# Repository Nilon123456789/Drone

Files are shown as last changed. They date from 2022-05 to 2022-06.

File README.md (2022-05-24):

# Drone
An open source multi-use drone made with arduino and 3d printing

Features

- Simple to use
- Easily editable
- Versatile

## Libraries

This project uses these following libraries

| Library | GitHub page |
| --- | --- |
| TinyMPU6050 | https://github.com/gabriel-milan/TinyMPU6050 |
| Servo | https://github.com/arduino-libraries/Servo |

## Require parts
Wearing or 3d printed part may need to be modified to suit other parts

| Part | quantity |
| --- | --- |
| Arduino nano | 1 |
| MPU 6050 | 1 |
| Pref board | 150x100mm |
| PLA or PETG | ≈ 1 kg |
| Jumper wire | pqt. 10 |
| Break away pins | pqt 25|
| zip ties | pqt 30 |
| M2.5 stand off | 6 |
| M3 nuts | 32 |
| M3x12 bolts | 32 |

## Build instruction
Coming later

## 3D printing instruction 
Coming later

## Programation and Setup
Coming later

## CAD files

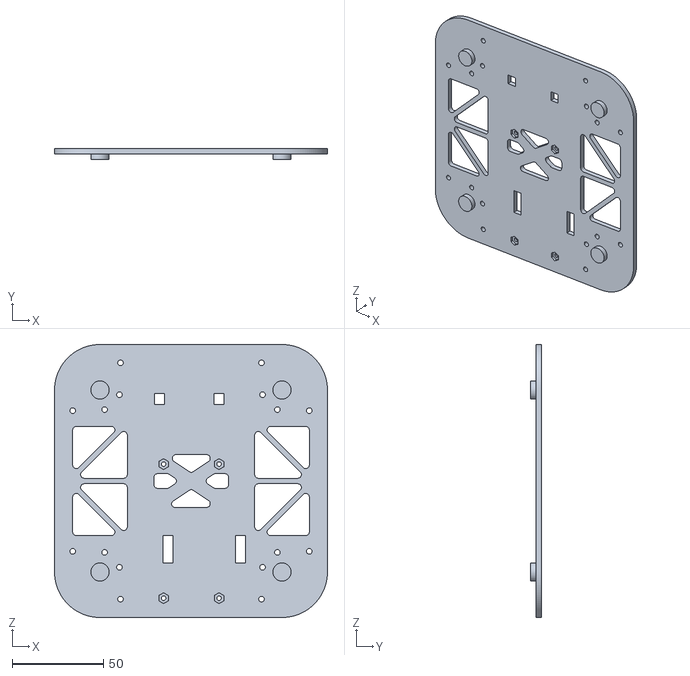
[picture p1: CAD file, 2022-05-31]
STL files/Drone/01-Main_Frame.stl
150.0 x 6.00 x 150.0

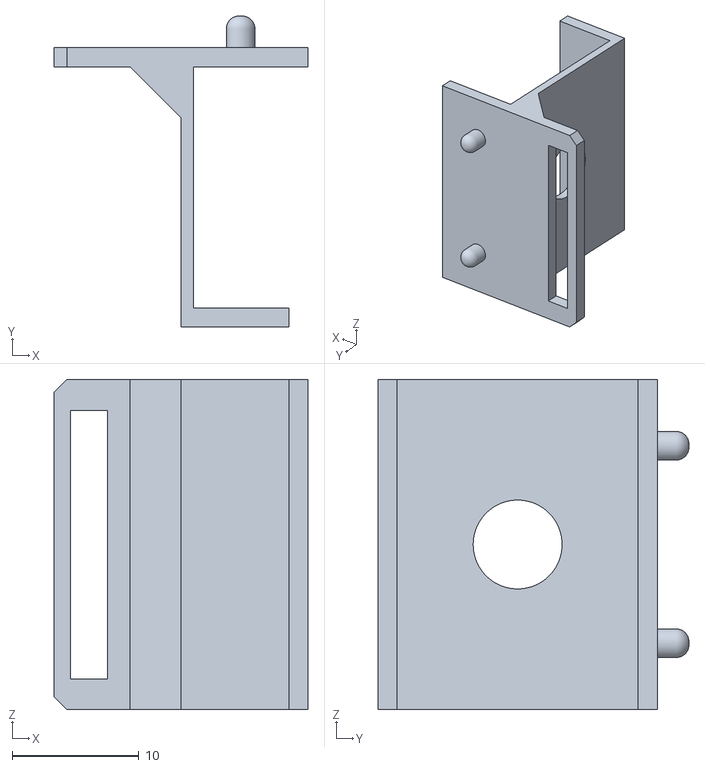
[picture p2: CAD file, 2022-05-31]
STL files/Balance/01-MPU_Holder.stl
20.0 x 24.5 x 26.0

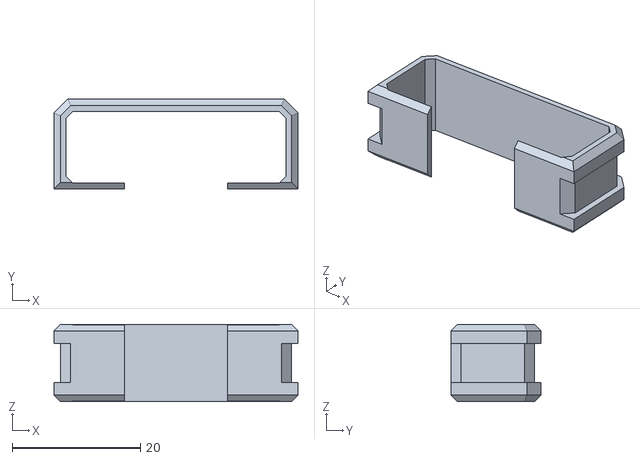
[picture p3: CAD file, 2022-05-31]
STL files/Drone/03-RC_Holder.stl
38.0 x 14.0 x 12.0

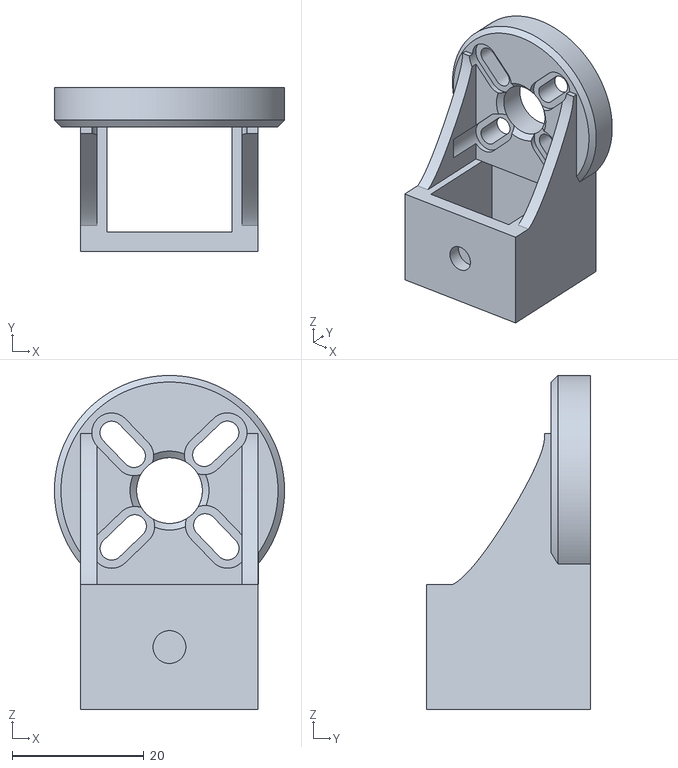
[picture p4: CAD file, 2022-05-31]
STL files/Balance/02-Motor_Holder.stl
35.0 x 25.0 x 50.8

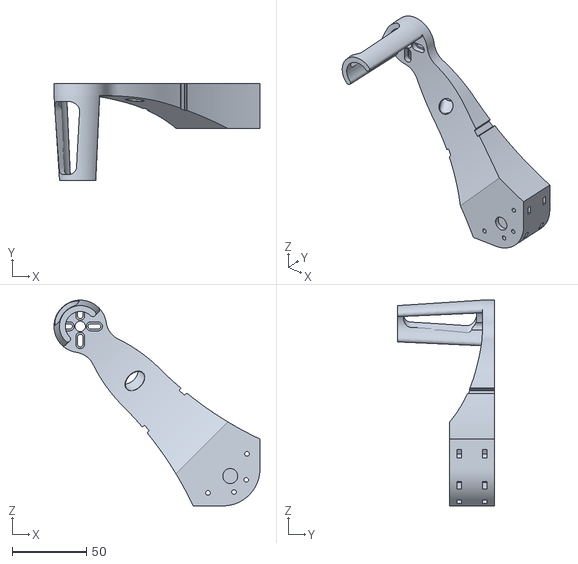
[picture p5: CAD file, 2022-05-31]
STL files/Drone/02-Arms.stl
138.6 x 65.0 x 138.5

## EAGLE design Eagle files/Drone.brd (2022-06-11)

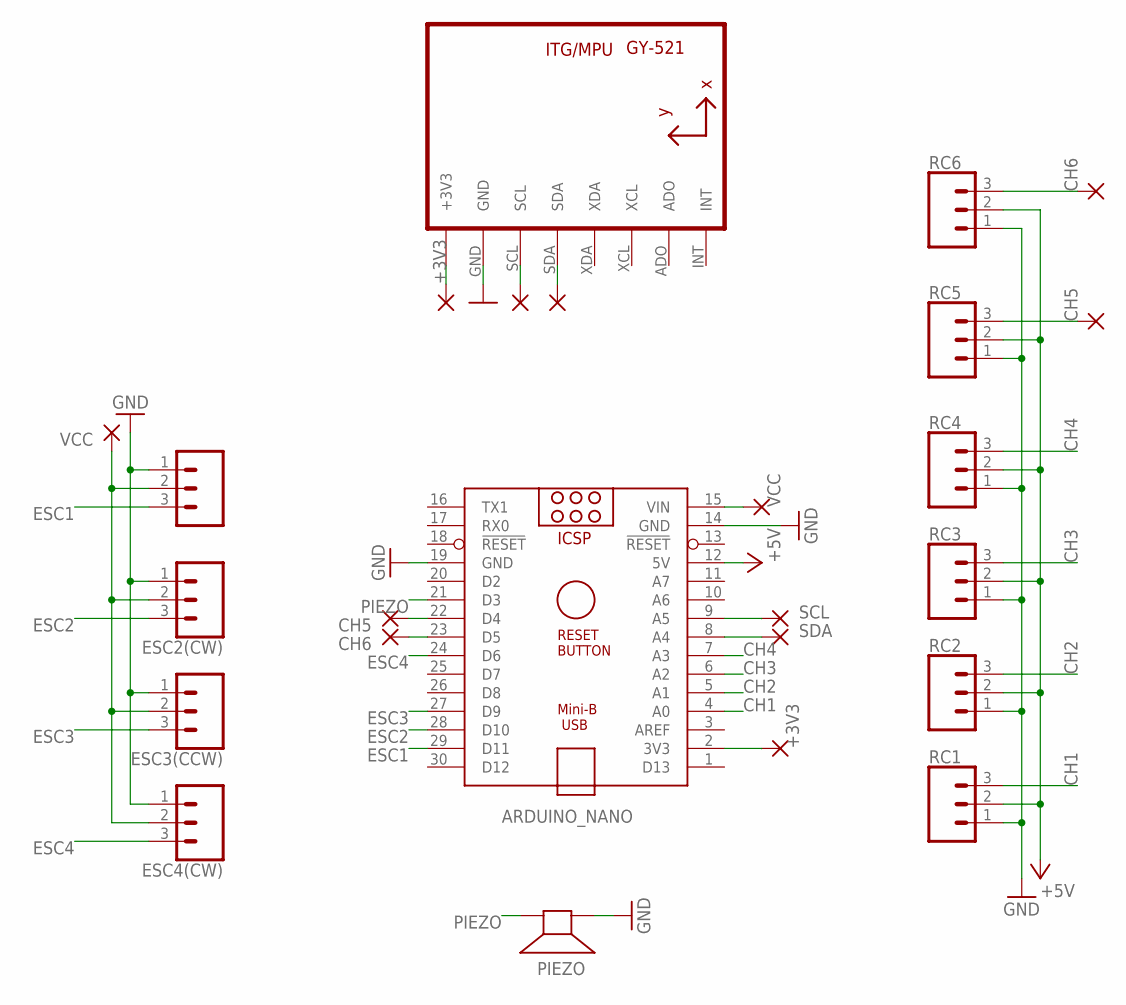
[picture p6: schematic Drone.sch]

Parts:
+3V3-1, +3V3-2: +3V3; 1,6/0,8
ARDUINO_NANO: ARDUINO_NANO
CH5, CH5-2, CH6, CH6-2: SCL; 1,6/0,8
ECS1(CCW): CONN_03; 1X03
ESC2(CW), ESC3(CCW), ESC4(CW): CONN_03; 1X03
PIEZO: SPEAKER/AL60P; AL60P
RC1, RC2, RC3, RC4, RC5, RC6: CONN_03; 1X03
SCL: SCL; 1,6/0,8
SCL-2: SCL; 1,6/0,8
SDA: SDA; 1,6/0,8
SDA-2: SDA; 1,6/0,8
U1: GY-521MPU6050; GY-521
VCC-1, VCC-2: VCC; 1,6/0,8

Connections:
+3V3: +3V3-1.1, +3V3-2.1, ARDUINO_NANO.2 (3V3), U1.VCC (+3V3)
+5V: ARDUINO_NANO.12 (5V), RC1.2, RC2.2, RC3.2, RC4.2, RC5.2, RC6.2
CH1: ARDUINO_NANO.4 (A0), RC1.3
CH2: ARDUINO_NANO.5 (A1), RC2.3
CH3: ARDUINO_NANO.6 (A2), RC3.3
CH4: ARDUINO_NANO.7 (A3), RC4.3
CH5: ARDUINO_NANO.22 (D4), CH5.1, CH5-2.1, RC5.3
CH6: ARDUINO_NANO.23 (D5), CH6.1, CH6-2.1, RC6.3
ESC1: ARDUINO_NANO.29 (D11), ECS1(CCW).3
ESC2: ARDUINO_NANO.28 (D10), ESC2(CW).3
ESC3: ARDUINO_NANO.27 (D9), ESC3(CCW).3
ESC4: ARDUINO_NANO.24 (D6), ESC4(CW).3
GND: ARDUINO_NANO.14 (GND), ARDUINO_NANO.19 (GND), ECS1(CCW).1, ESC2(CW).1, ESC3(CCW).1, ESC4(CW).1, PIEZO.1 (+), RC1.1, RC2.1, RC3.1, RC4.1, RC5.1, RC6.1, U1.GND
PIEZO: ARDUINO_NANO.21 (D3), PIEZO.2 (-)
SCL: ARDUINO_NANO.9 (A5), SCL.1, SCL-2.1, U1.SCL
SDA: ARDUINO_NANO.8 (A4), SDA.1, SDA-2.1, U1.SDA
VCC: ARDUINO_NANO.15 (VIN), ECS1(CCW).2, ESC2(CW).2, ESC3(CCW).2, ESC4(CW).2, VCC-1.1, VCC-2.1

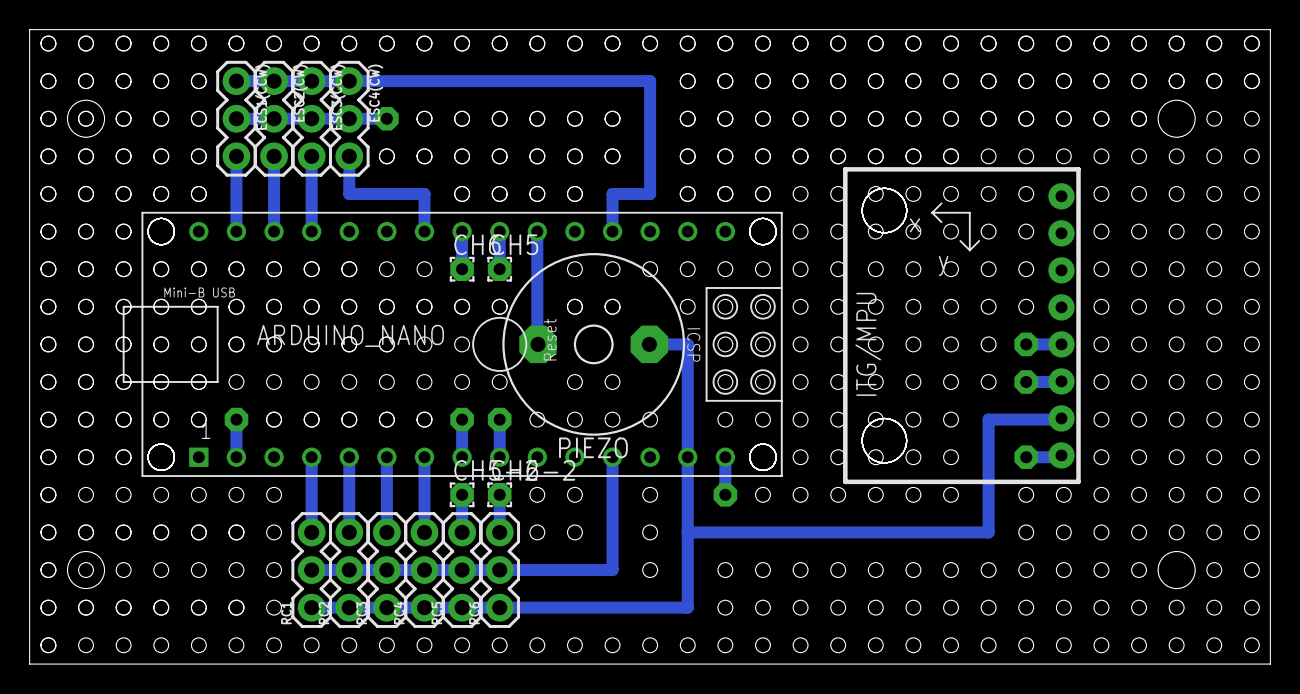
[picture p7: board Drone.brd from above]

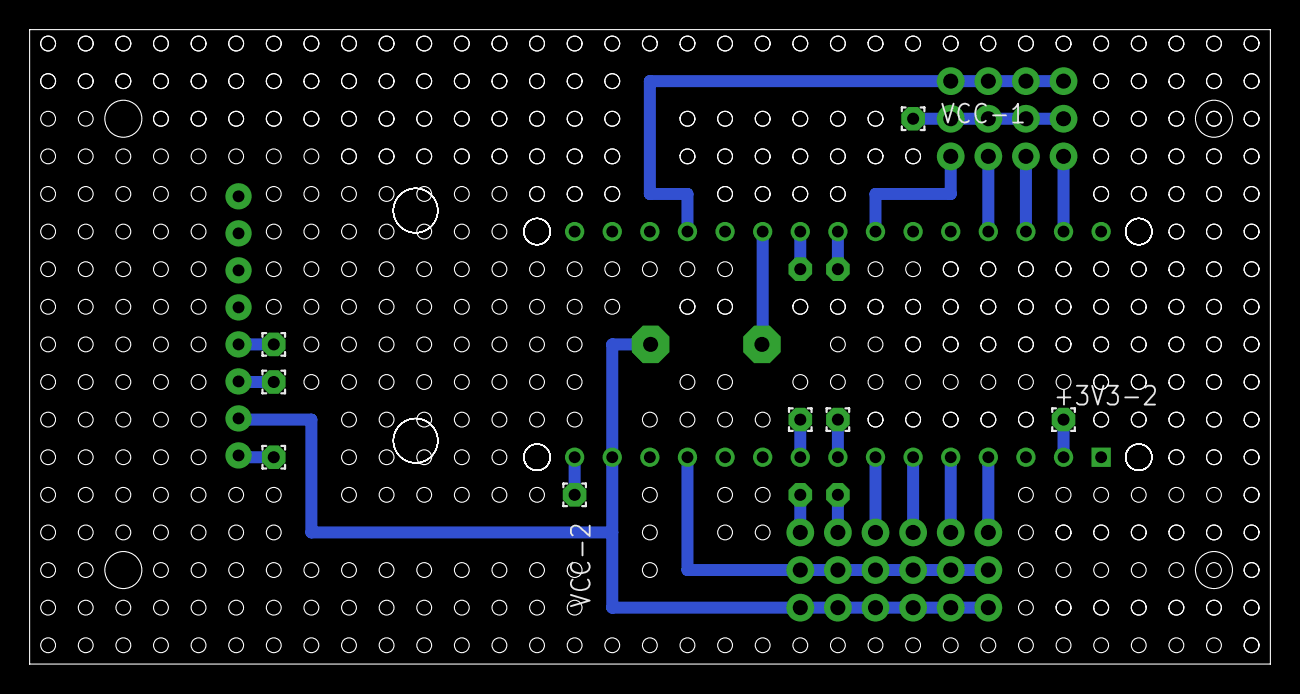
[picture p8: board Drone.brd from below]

Board: 2 copper layers, 83.8 x 42.9 mm, 25 parts (8 on the bottom side), 17 nets.

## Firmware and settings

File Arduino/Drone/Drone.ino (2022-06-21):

/*
 * This is the Main script of the Drone
 * Please run the setup script first to
 * Save the gyro and reciver vales.
 * Don't forget to check the pin of the
 * component and the wiring. Also it is
 * sugested that you run the balance script
 * to setup the pid values.
 * 
 * 
 * Made by Nils Lahaye 2022
 */

#include "Config.h"

/******************************************/
/*            GLOBAL VARIABLES            */
/******************************************/

/*MPU6050 VARIABLE*/
MPU6050 mpu (Wire);

/*ESCs VARIABLES*/
Servo ESC_FL, ESC_FR, ESC_BL, ESC_BR;
float ESC_val_FL = 1000, ESC_val_FR  = 1000, ESC_val_BL  = 1000, ESC_val_BR  = 1000;

/*PIDs VARIABLES*/
float pid_i_mem_Roll, pid_setpoint_Roll, gyro_input_Roll, pid_output_Roll, pid_last_d_error_Roll; //Roll PID calcul value
float pid_i_mem_Pitch, pid_setpoint_Pitch, gyro_input_Pitch, pid_output_Pitch, pid_last_d_error_Pitch; //Pitch PID calcul value
float pid_i_mem_Yaw, pid_setpoint_Yaw, gyro_input_Yaw, pid_output_Yaw, pid_last_d_error_Yaw; //Yaw PID calcul value

/*BOOT VARIABLES*/
bool isReady = false;

/*ARMING AND ALARM VARIABLES*/
bool armed = false;

/*Is the drone upside down*/
bool upSideDown = false;

unsigned long previousAlarmTime = 0L;
unsigned long previousUpSideAlarmTime = 0L;
int alarmIndex = 0;
bool upSideAlarm = false;

/*******************************/
/*            SETUP            */
/*******************************/

void setup() {
  Serial.begin(115200);

  tone(PiezoPin, 2000, 250);


  Serial.println("Seting up mpu6050");
  mpu.Initialize();
  mpu.SetGyroOffsets(GyroX,GyroY,GyroZ); //Seting the gyrooffset from the Config.h file
  Serial.println("");
  mpu.Calibrate();

  tone(PiezoPin, 2000, 250);
  delay(300);
  tone(PiezoPin, 2000, 250);
  
  Serial.println("Seting up ESCs");
  
  //Set the pin for each ESC
  ESC_FL.attach(EscPinFR);
  ESC_FR.attach(EscPinFL);
  ESC_BL.attach(EscPinBL);
  ESC_BR.attach(EscPinBR);
  Serial.print('>');
  
  //Set the ESC to idle speed
  ESC_FL.writeMicroseconds(escIdle); 
  ESC_FR.writeMicroseconds(escIdle);
  ESC_BL.writeMicroseconds(escIdle); 
  ESC_BR.writeMicroseconds(escIdle);
  Serial.print('>');

  for(int i; i < 10; i++) {//Delay with feedback to let the esc boot
    Serial.print('*');
    delay(1000);
  }
  Serial.println("");

  tone(PiezoPin, 2000, 250);
  delay(300);
  tone(PiezoPin, 2000, 250);
  delay(300);
  tone(PiezoPin, 2000, 250);
  
  Serial.println("Seting up Reciver");

  pinMode(ThrotlePin, INPUT);
  pinMode(RollPin, INPUT);
  pinMode(PitchPin, INPUT);
  pinMode(YawPin, INPUT);
  pinMode(Extra1Pin, INPUT);
  pinMode(Extra2Pin, INPUT);

  Booted();

  isReady = true;
  Serial.println("Ready");
}


/*******************************/
/*              LOOP           */
/*******************************/

void loop() {
  if(!isReady) return;//Wait for ready

  //Check whether the drone alarm switch is on or not
  int _alarmSwitchVal = map(pulseIn(Extra2Pin,HIGH),extra2Min,extra2Max,0,10);

  if(_alarmSwitchVal > 5) { 
    
    Alarm();  //Play the alarm sound

  }
  //Check whether the drone is Armed or not
  int _armedSwitchVal = map(pulseIn(Extra1Pin,HIGH),extra1Min,extra1Max,0,10);

  if(!armed)
  {
    if(_armedSwitchVal > 5 && !armed) { 
    
    Armed();  //Drone just armed (play armed sound)
    armed = true; //Save the curent armed switch state
    
    }
    else return ;
  }
  else if (_armedSwitchVal < 5 && armed) { 
    
    Disarmed();  //Drone just disarmed (play disarmed sound)
    armed = false; //Save the curent armed switch state
    return;
    
  }
  
  GetAngles(); //Get the XYZ angle of the MPU6050

//If the drone is upsidedown shutoff and play a sound
  if(upSideDown)
  {
    ESC_FL.writeMicroseconds(escIdle); 
    ESC_FR.writeMicroseconds(escIdle);
    ESC_BL.writeMicroseconds(escIdle); 
    ESC_BR.writeMicroseconds(escIdle);
    UpSideDownAlarm();
    return;
  }

  //Get the current throttle value
  int _throttle = map(pulseIn(ThrotlePin,HIGH),throttleMin,throttleMax,escIdle,escMax);

  if(_throttle <= escMin - 50)
  {
    ESC_FL.writeMicroseconds(escIdle); 
    ESC_FR.writeMicroseconds(escIdle);
    ESC_BL.writeMicroseconds(escIdle); 
    ESC_BR.writeMicroseconds(escIdle);
    return;
  }

  //Set the new setpoint from the controller
  pid_setpoint_Roll = map(pulseIn(RollPin, HIGH),rollMin,rollMax,rollMinAngle,rollMaxAngle);
  pid_setpoint_Pitch = map(pulseIn(PitchPin, HIGH),pitchMin,pitchMax,pitchMinAngle,pitchMaxAngle);
  pid_setpoint_Yaw = pid_setpoint_Yaw + map(pulseIn(YawPin, HIGH),yawMin,yawMax,yawMinAngle,yawMaxAngle) * yawStrenght;

  //Make sure the pid_setpoint_Yaw is in the range of the MPU6050
  if (pid_setpoint_Yaw > 180) pid_setpoint_Yaw = -180 + (pid_setpoint_Yaw - 180);
  if (pid_setpoint_Yaw < -180) pid_setpoint_Yaw = 180 + (pid_setpoint_Yaw + 180);

  //Compute the pid values
  pidCompute();

  //Seting the new ESC val from the pid output
  ESC_val_FL = _throttle + pid_output_Roll + pid_output_Pitch + pid_output_Yaw + escTunerFL;
  ESC_val_FR = _throttle - pid_output_Roll + pid_output_Pitch - pid_output_Yaw + escTunerFR;
  ESC_val_BL = _throttle + pid_output_Roll - pid_output_Pitch - pid_output_Yaw + escTunerBL;
  ESC_val_BR = _throttle - pid_output_Roll - pid_output_Pitch + pid_output_Yaw + escTunerBR;
  
  //Make sure motor val ar in range
  if (ESC_val_FL < escMin) ESC_val_FL = escMin;
  if (ESC_val_FR < escMin) ESC_val_FR = escMin;
  if (ESC_val_BL < escMin) ESC_val_BL = escMin;
  if (ESC_val_BR < escMin) ESC_val_BR = escMin;

  if(ESC_val_FL > escMax)ESC_val_FL = escMax;
  if(ESC_val_FR > escMax)ESC_val_FR = escMax;  
  if(ESC_val_BL > escMax)ESC_val_BL = escMax;
  if(ESC_val_BR > escMax)ESC_val_BR = escMax; 
  
  //Write the ESC values
  ESC_FL.writeMicroseconds(ESC_val_FL);
  ESC_FR.writeMicroseconds(ESC_val_FR);
  ESC_BL.writeMicroseconds(ESC_val_BL);
  ESC_BR.writeMicroseconds(ESC_val_BR);

}

/******************************************/
/*            CUSTOM FUCNTIONS            */
/******************************************/

//Get XYZ angles form the MPU6050
void GetAngles() 
{
  //Get the new gyro value
  mpu.Execute();

  //Set the angles in an array
  float mpuAngles[3] = {mpu.GetAngX(), mpu.GetAngY(), mpu.GetAngZ()};

  //Set the new gyro Value based on the axis
  gyro_input_Roll = mpuAngles[0] * mappedAxis[0][0] + mpuAngles[1] * mappedAxis[0][1] + mpuAngles[2] * mappedAxis[0][2];
  gyro_input_Pitch = mpuAngles[0] * mappedAxis[1][0] + mpuAngles[1] * mappedAxis[1][1] + mpuAngles[2] * mappedAxis[1][2];
  gyro_input_Yaw = mpuAngles[0] * mappedAxis[2][0] + mpuAngles[1] * mappedAxis[2][1] + mpuAngles[2] * mappedAxis[2][2];

  //Check if upside down
  if (gyro_input_Pitch > 90 || gyro_input_Roll > 90) upSideDown = true;
  else upSideDown = false;
}

//Compute all of the pid values
void pidCompute()
{
    float _pid_error;

    //Roll
    _pid_error = gyro_input_Roll - pid_setpoint_Roll; 
    pid_i_mem_Roll += pid_i_Roll * _pid_error;
    if(pid_i_mem_Roll > pid_max_Roll) pid_i_mem_Roll = pid_max_Roll;
    else if(pid_i_mem_Roll < pid_max_Roll * -1) pid_i_mem_Roll = pid_max_Roll * -1;

    pid_output_Roll = pid_p_Roll * _pid_error + pid_i_mem_Roll + pid_d_Roll * (_pid_error - pid_last_d_error_Roll);
    if(pid_output_Roll > pid_max_Roll) pid_output_Roll = pid_max_Roll;
    else if(pid_output_Roll < pid_max_Roll * -1) pid_output_Roll = pid_max_Roll * -1;

    pid_last_d_error_Roll = _pid_error;


    //Pitch
    _pid_error = gyro_input_Pitch - pid_setpoint_Pitch;
    pid_i_mem_Pitch += pid_i_Pitch * _pid_error;
    if(pid_i_mem_Pitch > pid_max_Pitch) pid_i_mem_Pitch = pid_max_Pitch;
    else if(pid_i_mem_Pitch < pid_max_Pitch * -1) pid_i_mem_Pitch = pid_max_Pitch * -1;

    pid_output_Pitch = pid_p_Pitch * _pid_error + pid_i_mem_Pitch + pid_d_Pitch * (_pid_error - pid_last_d_error_Pitch);
    if(pid_output_Pitch > pid_max_Pitch) pid_output_Pitch = pid_max_Pitch;
    else if(pid_output_Pitch < pid_max_Pitch * -1) pid_output_Pitch = pid_max_Pitch * -1;

    pid_last_d_error_Pitch = _pid_error;


    //Yaw
    _pid_error = gyro_input_Yaw - pid_setpoint_Yaw;
    pid_i_mem_Yaw += pid_i_Yaw * _pid_error;
    if(pid_i_mem_Yaw > pid_max_Yaw) pid_i_mem_Yaw = pid_max_Yaw;
    else if(pid_i_mem_Yaw < pid_max_Yaw * -1) pid_i_mem_Yaw = pid_max_Yaw * -1;

    pid_output_Yaw = pid_p_Yaw * _pid_error + pid_i_mem_Yaw + pid_d_Yaw * (_pid_error - pid_last_d_error_Yaw);
    if(pid_output_Yaw > pid_max_Yaw) pid_output_Yaw = pid_max_Yaw;
    else if(pid_output_Yaw < pid_max_Yaw * -1) pid_output_Yaw = pid_max_Yaw * -1;

    pid_last_d_error_Yaw = _pid_error;
}

//Play the boot sound
void Booted()
{
  tone(PiezoPin, 500, 100);
 	delay(100);
 	tone(PiezoPin, 1500, 100);
  delay(100);
	tone(PiezoPin,  2000, 100);
 	delay(50);
 	tone(PiezoPin, 2500, 100);
 	delay(250);
 	noTone(PiezoPin);
}

//Play the Alarm sound
void Alarm()
{
  unsigned long _currentTime = millis();
  if (_currentTime - previousAlarmTime >= 100 && alarmIndex == 0) 
  {
    tone(PiezoPin, 1000, 100);
    alarmIndex++;
  }
  else if (_currentTime - previousAlarmTime >= 100*2 && alarmIndex == 1) 
  {
    tone(PiezoPin, 2000, 100);
    alarmIndex++;
  }
  else if (_currentTime - previousAlarmTime >= 100*3 && alarmIndex == 2) 
  {
    tone(PiezoPin, 3000, 100);
    alarmIndex++;
  }
  else if (_currentTime - previousAlarmTime >= 100*5 && alarmIndex == 3) 
  {
    previousAlarmTime = _currentTime;
    alarmIndex = 0;
  } 
}

//Play the Armed sound
void Armed()
{
  tone(PiezoPin, 500, 100);
 	delay(100);
 	tone(PiezoPin, 1000, 100);
  delay(100);
 	tone(PiezoPin,  2000, 100);
 	delay(100);
 	noTone(PiezoPin);

}

//Play the Disarmed sound and Stop all motors
void Disarmed()
{
  //Write the ESC stop
  ESC_FL.writeMicroseconds(escIdle);
  ESC_FR.writeMicroseconds(escIdle);
  ESC_BL.writeMicroseconds(escIdle);
  ESC_BR.writeMicroseconds(escIdle);

  tone(PiezoPin, 2000, 100);
	delay(100);
 	tone(PiezoPin, 1000, 100);
 	delay(100);
	tone(PiezoPin, 2500, 100);
 	delay(100);
 	noTone(PiezoPin);
}

//Play the Upside down alarm sound
void UpSideDownAlarm()
{
  unsigned long _currentTime = millis();
  if (_currentTime - previousUpSideAlarmTime >= 100 && !upSideAlarm) 
  {
    tone(PiezoPin, 1000, 100);
     upSideAlarm = true;
  }
  else if (_currentTime - previousAlarmTime >= 100*2 && upSideAlarm) 
  {
    tone(PiezoPin, 1000, 100);
    previousAlarmTime = _currentTime;
    upSideAlarm = false;
  }
}

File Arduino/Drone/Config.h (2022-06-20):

/************************************/
/*         Included Libraries       */
/************************************/
#include <Arduino.h>
#include <TinyMPU6050.h>
#include <Servo.h>

/************************************/
/*              Pinout              */
/************************************/
//                                                               (2)   (1)
//ESC                                                            CW    CCW
#define EscPinFR 11 //CCW  (1)                                    ╲  ╱
#define EscPinFL 10 //CW (2)                                        ▉     ↑ forward
#define EscPinBR 9 //CW  (3)                                      ╱  ╲
#define EscPinBL 6 //CCW   (4)                                 CCW    CW
//                                                               (4)    (3)
//Remote
#define ThrotlePin A0
#define RollPin A1
#define PitchPin A2  
#define YawPin A3
#define Extra1Pin 4
#define Extra2Pin 5

//Piezo
#define PiezoPin 3

/************************************/
/*           Variables              */
/************************************/

/******PID Values******/
extern const double pid_p_Roll=1.73, pid_i_Roll=0.05, pid_d_Roll=13.47; //PID val for roll
extern const double pid_p_Pitch=1.73, pid_i_Pitch=0.05, pid_d_Pitch=13.47; //PID val for pitch
extern const double pid_p_Yaw=3.0, pid_i_Yaw=0.04, pid_d_Yaw=0.0; //PID val for yaw

extern const int pid_max_Roll = 400; //Max PID output for roll
extern const int pid_max_Pitch = 400; //Max PID output for pitch
extern const int pid_max_Yaw = 400; //Max PID output for yaw

/******ESC Values******/
extern const int escIdle = 1000; //ESC idle speed
extern const int escMin = 1100; //ESC min working speed (for all esc)
extern const int escMax = 2000; //ESC max working spee (for all esc)
//Value to tune the ESC if there not properly calibrated
extern const int escTunerFL = -100;
extern const int escTunerFR = 0;
extern const int escTunerBL = -100;
extern const int escTunerBR = 0;

/******RC Values******/
//If axis are inversed switch the min and the max
extern const int throttleMin=996, throttleMax=1988;
extern const int rollMin=1010, rollMax=1986;
extern const int pitchMin=994, pitchMax=1983;
extern const int yawMin=995, yawMax=1978;
extern const int extra1Min=995, extra1Max=1978;
extern const int extra2Min=995, extra2Max=1978;
//RC value mapping
extern const int rollMinAngle=-65, rollMaxAngle=65;
extern const int pitchMinAngle=-45, pitchMaxAngle=45;
extern const int yawMinAngle=-10, yawMaxAngle=10;
//Yaw move speed
extern const float yawStrenght = 0.1;

extern const int mappedAxis[3][3] = //Place a 1 or -1 (to invert) to link the mpu input (on the top) to the axis output (on the side), one 1 max per row and colums
{
//  X , Y , Z
  {'0','1','0'}, //Pitch
  {'1','0','0'}, //Roll
  {'0','0','1'} //Yaw
};

/******MPU6050 Values******/

extern const float GyroX=-109.47, GyroY=51.02, GyroZ=-109.47;//Gyro offset 

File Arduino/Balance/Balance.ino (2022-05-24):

/*
 * This script is for the balance project 
 * to test and tweak the roll / pitch pid value 
 * refer to manual to see how to setup the rig
 * 
 * Don't forget to setup the right pin in the Config.h file
 * See the config.h file to tweak the PID values
 * 
 * 
 * Made by Nils Lahaye 2021
 */


#include "Config.h"

/******************************************/
/*            GLOBAL VARIABLES            */
/******************************************/

MPU6050 mpu (Wire);

Servo ESC_FL, ESC_FR;
float ESC_val_FL, ESC_val_FR;


float pid_i_mem_Roll, pid_setpoint_Roll, gyro_input_Roll, pid_output_Roll, pid_last_d_error_Roll; //Roll PID calcul value

double throttle=1300; //initial value of throttle to the motors

bool isReady = false;

/*******************************/
/*            CODE             */
/******************************/
void setup() {
  Serial.begin(115200);
  
  Serial.println(F("\nSend any character to begin : "));
  while (Serial.available() && Serial.read()); // empty buffer
  while (!Serial.available());                 // wait for data
  while (Serial.available() && Serial.read()); // empty buffer again

  Serial.println("Seting up mpu6050"); 
  mpu.Initialize();
  mpu.SetGyroOffsets(GyroX,GyroY,GyroZ); //Seting the gyrooffset from the Config.h file
  Serial.println("");

  
  Serial.println("Seting up ESCs");

  //Set the pin for each esc
  ESC_FL.attach(EscPinFR);
  ESC_FR.attach(EscPinFL);
  Serial.print('>');

  //Set esc to there idle speed
  ESC_FL.writeMicroseconds(escIdle); 
  ESC_FR.writeMicroseconds(escIdle);
  Serial.print('>');

  for(int i; i < 10; i++) {//Delay with feedback to let the esc boot
    Serial.print('*');
    delay(500);
  }
  Serial.println("");

  
  Serial.println("Seting up Reciver");

  pinMode(ThrotlePin, INPUT);
  pinMode(RollPin, INPUT);


  isReady = true;
  Serial.println("Ready");
}

void loop() {
  if(!isReady) return;//Wait for ready

  //Get the gyro value
  mpu.Execute();
  
  
  float x = mpu.GetAngX(); //Get the x angle
  gyro_input_Roll = x; //Set the gyro angle for the PID
  
  int roll = map(pulseIn(RollPin, HIGH),rollMin,rollMax,-65,65); //Get the roll value
  pid_setpoint_Roll = roll; //Set the setpoint for the roll 

  pidCompute(); //compute PID
  
  throttle = map(pulseIn(ThrotlePin,HIGH),throttleMin,throttleMax,escMin,escMax); //Get the current throttle

  //Set the new ESC val
  ESC_val_FL = throttle + pid_output_Roll;
  ESC_val_FR = throttle - pid_output_Roll;
  
  
  
  //Make sure esc val ar in range
  if (ESC_val_FL < escMin) ESC_val_FL = escMin;
  if (ESC_val_FR < escMin) ESC_val_FR = escMin;

  if(ESC_val_FL > escMax)ESC_val_FL = escMax;
  if(ESC_val_FR > escMax)ESC_val_FR = escMax;  
  
  //Write the ESC values
  ESC_FL.writeMicroseconds(ESC_val_FL);
  ESC_FR.writeMicroseconds(ESC_val_FR);


  //Print for debuging
  Serial.print(pid_p_Roll);
  Serial.print("\t");
  Serial.print(pid_d_Roll);
  Serial.print("\t");
  Serial.print("\t");
  Serial.print(pid_output_Roll);
  Serial.print("\t");
  Serial.print(ESC_val_FL);
  Serial.print("\t");
  Serial.print(ESC_val_FR);
  Serial.print("\t");
  Serial.print(pid_setpoint_Roll);
  Serial.print("\t");
  Serial.print(x);
  Serial.print("\t");
  Serial.println(throttle);
}


//Compute all of the pid values
void pidCompute()
{
    float _pid_error;

    //Roll
    _pid_error = gyro_input_Roll - pid_setpoint_Roll; 
    pid_i_mem_Roll += pid_i_Roll * _pid_error;
    if(pid_i_mem_Roll > pid_max_Roll)pid_i_mem_Roll = pid_max_Roll;
    else if(pid_i_mem_Roll < pid_max_Roll * -1)pid_i_mem_Roll = pid_max_Roll * -1;

    pid_output_Roll = pid_p_Roll * _pid_error + pid_i_mem_Roll + pid_d_Roll * (_pid_error - pid_last_d_error_Roll);
    if(pid_output_Roll > pid_max_Roll)pid_output_Roll = pid_max_Roll;
    else if(pid_output_Roll < pid_max_Roll * -1)pid_output_Roll = pid_max_Roll * -1;

    pid_last_d_error_Roll = _pid_error;
}

float mapfloat(float x, float in_min, float in_max, float out_min, float out_max)
{
  return (x - in_min) * (out_max - out_min) / (in_max - in_min) + out_min;
}

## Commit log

2022-05-31 Adding the F3d files and stl files
    [01-MPU_Holder.stl, 01-Main_Frame.stl, 02-Arms.stl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]
2022-06-10 Adding Board schematic & updating gitignore for eagle files
    [Drone.brd, Drone.sch]
2022-06-10 Updated Config.h and Drone.ino
    Adding Alarm sound if second input is switched
    Adding Arming switch
    Adding mapping for the mpu
    Adding booting sound
    Refactoring a bit of code
2022-06-11 Updated the Drone board files
    [Drone.brd, Drone.sch]
2022-06-20 Added seting to tune the power of individual ESC
    Added the escTuner variable to help equalize the strength of the ESC
2022-06-21 Adding an alarm and motor cutoff if drone is upside down

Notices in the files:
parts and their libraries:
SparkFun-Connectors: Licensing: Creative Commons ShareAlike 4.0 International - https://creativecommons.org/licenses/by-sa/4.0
